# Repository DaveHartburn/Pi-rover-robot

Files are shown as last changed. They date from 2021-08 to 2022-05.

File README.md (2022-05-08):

# Pi-rover-robot

Repository for main code, libraries, hardware testing and simulator for a Raspberry Pi based rover robot.

Can I create an autonomous rover robot that can navigate around the garden, tracking it's location with BLE beacons, using a camera and image analysis to detect the lawn edge and other sensors to find and avoid other obsticles around the garden? Originally conceived with the intention of making an automated lawn mower (which may still happen) but the build and automation challenges are far more interesting first.

Blog posts detailing hardware build and software development can be found at https://samndave.org.uk/ourdoc/pi-rover-robot-project/

## piroverlib

The heart of most Python scripts is piroverlib.py. This contains two classes, piRover and pwmMotor.

### piRover class

| Function | Details |
| --- | --- |
| init(<list>) | Called with multiple arguments (below), depending on what hardware is installed |
|  * name="string"	| Give your robot a name |
|  * left=[a,b]		| List of a and b pins for left motor(s) |
|  * right=[a,b]	|	List of a and b pins for right motor(s) |
|  * load=1		|	Return load values with data |
|  * wifi=1		|	Return wifi RSSI and noise with data |
|  * button=p | Defines a pushbutton attached to pin p |
|  * pico=True | Use a pico slave for functions such as ultrasonic and pan/tilt mount |
|  * magneto=True	| Use a LSM303AGR magnetometer for heading info |
| stop() | Instantly stops both motors |
| fwFull(sp) | Sets both motors to full speed. sp positive for forward, sp negative for backwards. Zero will perform a stop |
| fwSpeed(sp) | Sets both motors to the speed sp |
| drive(l,r) | Drives the motors forward by setting the motors to the l & r values |
| js(x,y) | Drives the motors according to an analog joystick x and y axis calibrated to -100 to 100 |
| spin(sp) | Spins the rover on it's axis according to speed. Positive=clockwise |
| chSpeed(l,r) | Change the left and right motors by the l and r amount |
| getSensorData() | Returns data from all defined sensors |
| readLoad() | Returns only the current load |
| readWifi() | Returns wifi signal and noise levels as a list/tuple |
| getSonic(n) | Returns the ultrasonic distance value for a specific sensor or all if n is negative/missing |
| panAngle(a) | Sets the pan angle to a |
| panLeft(a) | Pans the camera to the left (or right if a is negative) |
| panCentre(a) | Sets the camera pan and tilt to centre (default positions) |
| tiltAngle(a) | Sets the tilt angle to a |
| tiltUp(a) | Tilts the camera up by angle a (down if a is negative) |
| getButton() | Returns the state of the pushbutton (0=pressed) |
| LSM303AGR Functions: | |
| magNormalise(m) | Internal function to normalise to calibrated values |
| getHeading([a, i]) | Get heading and chassis tilt, optional a attempts with interval i |
| turnToHeading(h, [s, f]) | Turn to a heading h, with speed s and force direction (1,-1) optional |

### pwmMotor class

| Function | Details |
| --- | --- |
| init(a,b) | Called when new motor object is created with the motor A & B BCM pins |
| stopPWM() | Internal use only. Used to stop a running PWM object |
| stop() | Instantly stops the motor and disabled PWM on the pin |
| full(sp) | Sets the motor to full speed. sp positive for forward, sp negative for backwards. Zero will perform a stop |
| setSpeed(sp) | Use PWM to set an analog speed between -100 and 100, with negative being backwards |

### driveByQueue
 
driveByQueue.py is an interface which implements a ZMQ queue and accepts a simple text command language. It directly calls functions in piroverlib.py, allowing one or more applications to send commands to the rover (or read sensor data), without having to run multiple piRoverLibs which may conflict. This aids web interface driving and also allows remote control.

Commands are supplied as a comma seperated list and it is quite sensitive to formatting.
 
e.g. "`chspeed,10,-10`" will increase the left motor by 10% while decreasing the right motor by 10%.
 
| Command	| Arguments	| Function |
| --- | --- | --- |
| stop	| None	| Stop |
| fwfull	| speed | positive or negative integer	Both motors forward or reverse at full power |
| fwspeed	| speed | -100 to 100	Sets both motors to speed |
| chspeed |	l, r	| Value to change speed of left and right motor |
| drive	| l, r	| Set absolute values for left and right motor |
| js	| x,y | Values between -100 and 100, send x and y joystick values |
| spin	| speed | -100 to 100,	Spin clockwise (positive) or anti-clockwise at given speed |
| panangle | a or 'mid' | Sets the pan angle or sets to centre |
| panleft | a | Pans the camera to the left (or right if a is negative) |
| pancentre | a | Sets the camera pan and tilt to centre (default positions) |
| tiltAngle | a | Sets the tilt angle to a |
| tiltUp | a | Tilts the camera up by angle a (down if a is negative) |
| getsens |	None	| Return all sensor data |
| getsonic | [n] | Get only the ultrasonic sensors with key sonicDist. Option to supply specific sensor number |
| quit	| None	| Quit the server |

## GPIO Wiring ##

Direct GPIO connections
 
| Pin# | Value | Connection| Pin# | Value | Connection |
| - | - | - | - | - | - |
| 1 | 3V3 | Breadboard 3.3v | 2 | 5V | Breadboard 5v |
| 3 | GPIO2 (SDA1, I2C) | PCA9685 | 4 | 5V | - |
| 5 | GPIO3 (SCL1, I2C) | PCA9685 | 6 | GND | Breadboard GND |
| 7 | GPIO4 | Front US trig | 8 | GPIO14 | Rear US trig |
| 9 | GND | - | 10 | GPIO15 | Rear US echo |
| 11 | GPIO17 | Front US echo | 12 | GPIO18 | MDD3A M1A |
| 13 | GPIO27 | Pushbutton | 14 | GND | - |
| 15 | GPIO22 | - | 16 | GPIO23 | - |
| 17 | 3V3 | - | 18 | GPIO24 | - |
| 19 | GPIO10 | - | 20 | GND | - |
| 21 | GPIO9 | - | 22 | GPIO25 | - |
| 23 | GPIO11 | - | 24 | GPIO8 | - |
| 25 | GND | - | 26 | GPIO7 | - |
| 27 | GPIO0 | - | 28 | GPIO1 | - |
| 29 | GPIO5 | - | 30 | GND | - |
| 31 | GPIO6 | - | 32 | GPIO12 | MDD3A M1B |
| 33 | GPIO19 | MDD3A M2A | 34 | GND | - |
| 35 | GPIO19 | MDD3A M2B | 36 | GPIO16 | - |
| 37 | GPIO26 | - | 38 | GPIO20 | - |
| 39 | GND | - | 40 | GPIO21 | - |

## Pi Pico Wiring ##

 | Pin# | Value | Connection | Pin# | Value | Connection |
 | - | - | - | - | - | - |
 | 1 | GP0 (UART0 Tx) | Pi Serial Rx (GPIO 15) | 40 | VBUS | - |
 | 2 | GP1 (UART0 Rx) | Pi Serial Tx (GPIO 14) | 39 | VSYS | - |
 | 3 | GND | Breadboard GND | 38 | GND | - |
 | 4 | GP2 | Servo 0, lower pan/tilt | 37 | 3v3_EN | - |
 | 5 | GP3 | Servo 1, upper pan/tilt | 36 | 3V3(OUT) | - |
 | 6 | GP4 | - | 35 | ADC_VREF | - |
 | 7 | GP5 | - | 34 | GP28 | - |
 | 8 | GND | - | 33 | GND | - |
 | 9 | GP6 | - | 32 | GP27 | - |
 | 10 | GP7 | - | 31 | GP26 | - |
 | 11 | GP8 | - | 30 | RUN | Pushbutton to GND |
 | 12 | GP9 | - | 29 | GP22 | - |
 | 13 | GND | - | 28 | GND | - |
 | 14 | GP10 | - | 27 | GP21 | - |
 | 15 | GP11 | - | 26 | GP20 | - |
 | 16 | GP12 | - | 25 | GP19 | - |
 | 17 | GP13 | - | 24 | GP18 | - |
 | 18 | GND | - | 23 | GND | - |
 | 19 | GP14 | - | 22 | GP17 (I2C0 SCL) | - |
 | 20 | GP15 | - | 21 | GP16 (I2C0 SDA) | - |
 
## To Do

- [x] Drivable app over wifi, can we drive anywhere in range of wifi?
- [] Proximity detection. Add to HUD and autonomous driving avoiding obstacles
- [] Directional sensing. Can we detect which direction we are facing and add suitable functions for turn to angle?
- [] Software vs Hardware PWM, power draw and test motor controller power
- [] QR code recognition - act when the camera recognises a QR code
- [] BLE beacon - can it detect a beacon and locate it?
- [] BLE triangulation - what if there were 4 beacons, can we accurately find our location?

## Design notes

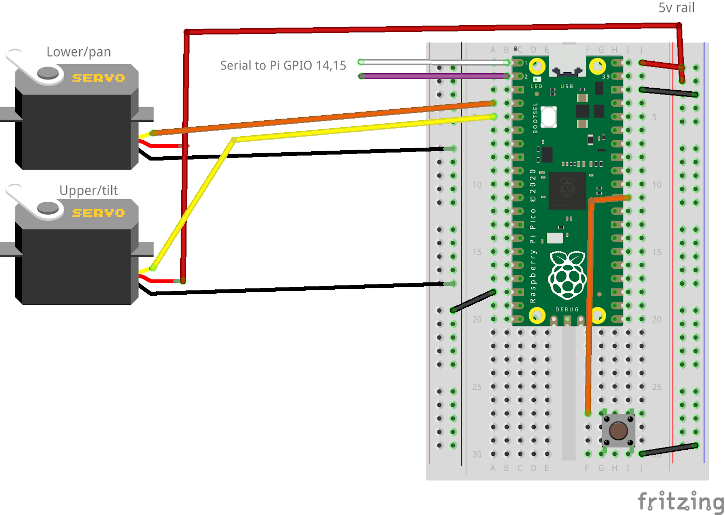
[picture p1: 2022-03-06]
schematics/pico_breadboard_bb.png

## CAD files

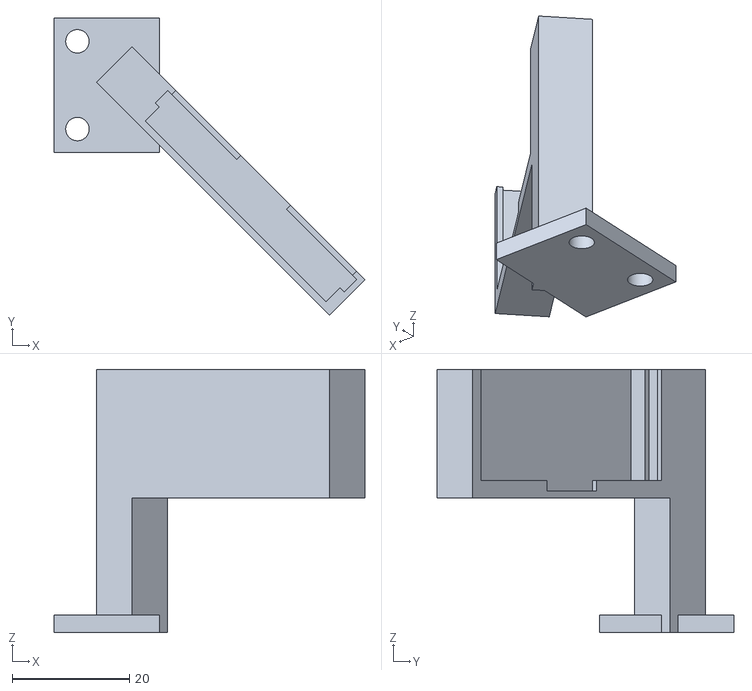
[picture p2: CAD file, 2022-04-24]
3dPrints/overWheelSR04_right.stl
53.1 x 50.8 x 45.0

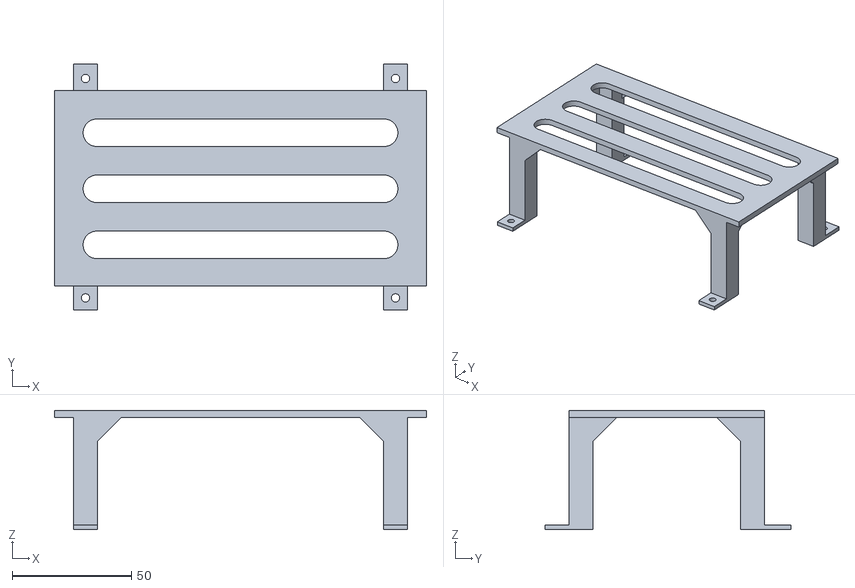
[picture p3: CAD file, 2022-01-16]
3dPrints/elevatedBBholder.stl
156.0 x 103.0 x 50.0

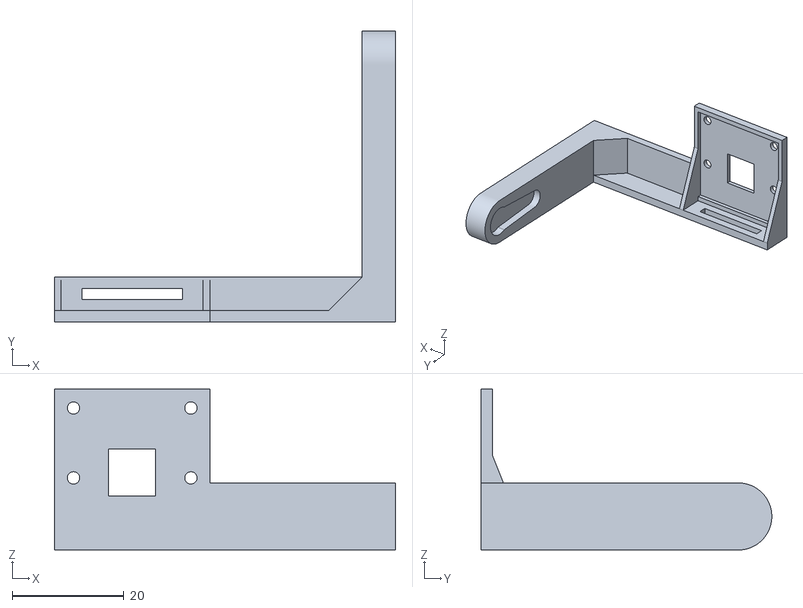
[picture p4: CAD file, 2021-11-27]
3dPrints/pan_tilt_cam_arm.stl
61.0 x 52.0 x 28.8

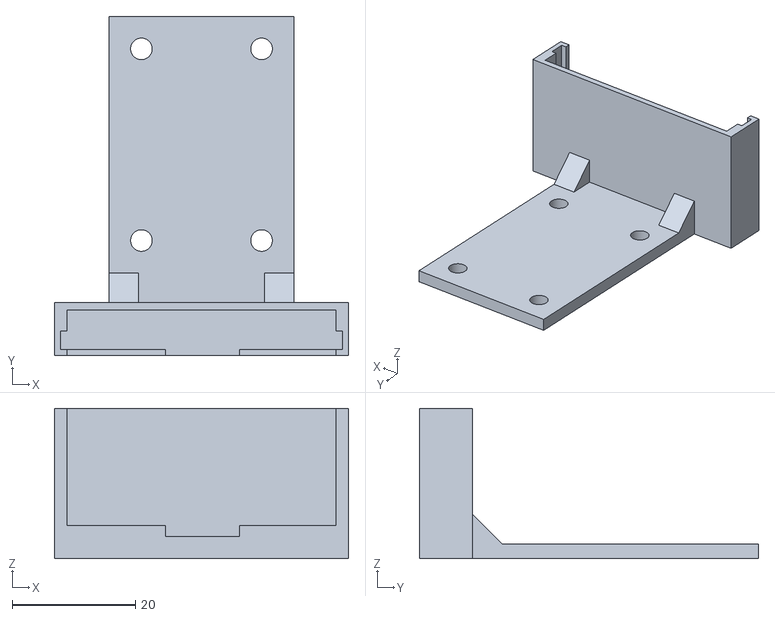
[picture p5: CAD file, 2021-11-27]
3dPrints/hc_sr04_mount.stl
47.7 x 55.0 x 24.4

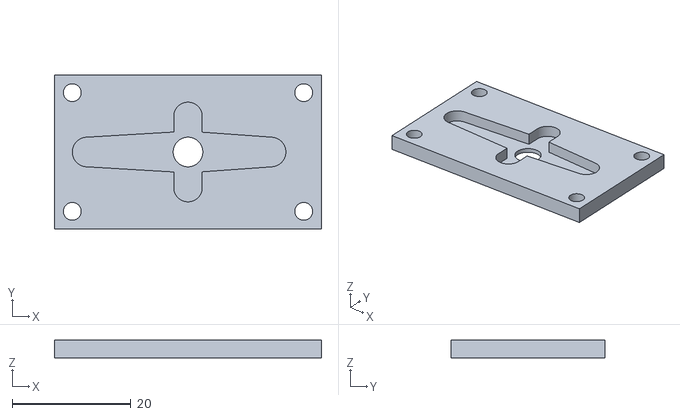
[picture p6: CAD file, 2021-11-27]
3dPrints/pan_tilt_mount_lower_base.stl
45.0 x 26.0 x 3.00

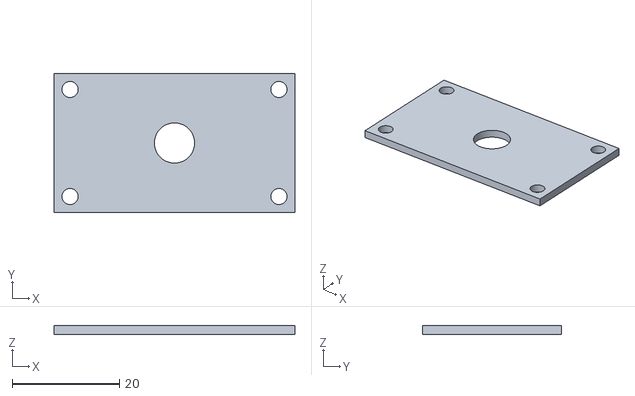
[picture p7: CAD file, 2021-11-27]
3dPrints/pan_tilt_mount_upper_base.stl
45.0 x 26.0 x 1.60

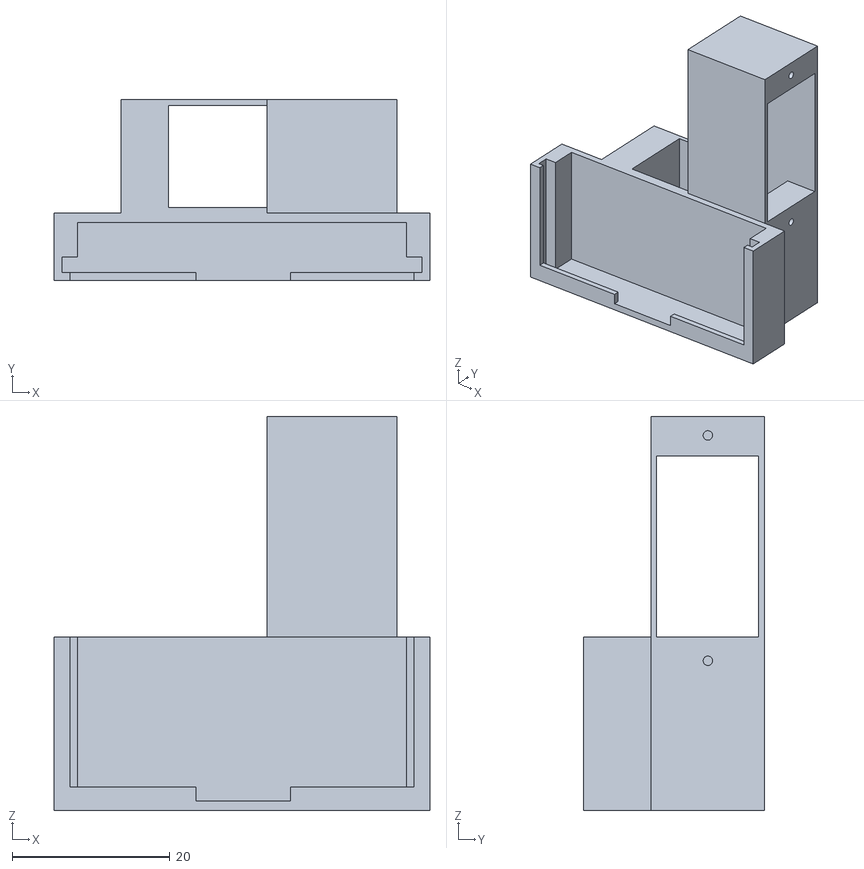
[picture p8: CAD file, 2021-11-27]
3dPrints/pan_tilt_mount_body.stl
47.7 x 23.0 x 50.0

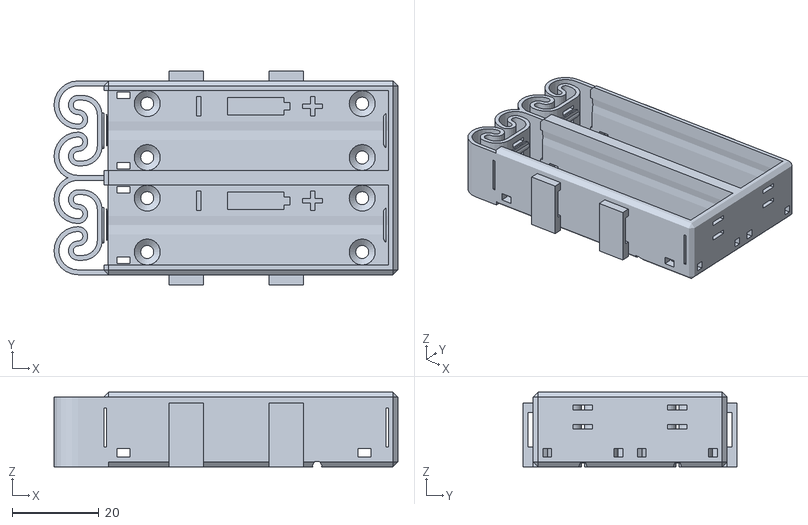
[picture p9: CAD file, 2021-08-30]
3dPrints/18650_nickle.stl
79.2 x 49.4 x 17.2

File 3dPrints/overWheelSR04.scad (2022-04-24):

/* HC-SR04 over wheel holder
 * For Pi Rover Robot
  */

$fn=256;

// What to show
showWheel=0;    // Will also show chassis
showSensor=0;
showHolder=1;

rightWheel=1;   // 1 for right wheel, 0 for left

sensorAngle=45;
sensHeight=45;

if(showWheel==1) {
    drawWheelChassis();
}

if(showSensor==1) {
    drawSensor();
}

if(showHolder==1) {
    if(rightWheel==1) {
        sensorHolder();
    } else {
        mirror([1,0,0]) {
            sensorHolder();
        }
    }
}

module sensorHolder() {
    w=45.3+2.4;     // Width of the main unit
    sd=8.6;   // Sensor holder depth
    shh=22;   // Sensor holder height

    plateTh=3;
    plateW=18;
    plateL=23;
    hole=4;     // Screw hole size

    // Sensor holder
    rotate([0,0,180-sensorAngle]) translate([1-w,-3,sensHeight-shh])  {
        // Sensor holder
        difference() {
            cube([w,sd,shh]);
            // slot
            translate([1,-1,1.2]) cube([45.3+0.4,5,shh+1]);
            translate([2,3,1.2]) cube([45.3+0.4-2,4.4,shh+5]);
        }
        // Retaining supports
        translate([0,0,1]) cube([18,1,2]);
        translate([30,0,1]) cube([17,1,2]);
        translate([1,0,0]) cube([1,1,shh]);
        translate([45.3+0.4,0,0]) cube([1,1,shh]);
        
        // Draw pole
        translate([w,0,shh-sensHeight]) {
            cube([sd,sd,sensHeight]);
        }
    }
    // Base plate
    translate([-plateW, sd/2-plateL/2-2, 0]) {
        difference() {
            cube([plateW,plateL,plateTh]);
            // Screw holes
            translate([hole,hole,-1]) {
                cylinder(h=plateTh+2, d=hole);
            }
            translate([hole,plateL-hole,-1]) {
                cylinder(h=plateTh+2, d=hole);
            }
        }
    }
}

module drawSensor() {
    translate([0,0,sensHeight]) {
        rotate([-90,0,-sensorAngle]) {
            hcsr04();
        }
    }
}

module drawWheelChassis() {
    // Chassis - very crude
    // Dimensions
    w=60;
    l=100;
    h=12;
    offset=16;  // How much lower is the board to the wheel?
    
    color("Peru") {
        translate([-w,-l/2,-h]) cube([w,l,h]);
    }
    diam=83;
    tyrew=33;
    color("darkgrey") {
        translate([0,0,offset-diam/2]) {
            rotate([0,90,0]) cylinder(d=diam, h=tyrew);
        }
    }
}

module hcsr04() {
    // Draws a HC-SR04 sensor module
    w=45.3;
    h=20.3;
    d=1.6;
    hole=1.5;
    ho=1.3; // Hole offset (same in X and Y);
    srdiam=16;
    difference() {
        color("darkblue") cube([w,h,d]);
        // Cut holes
        translate([ho,ho,-1]) cylinder(d=hole, h=d+2);
        translate([ho,h-ho,-1]) cylinder(d=hole, h=d+2);
        translate([w-ho,ho,-1]) cylinder(d=hole, h=d+2);
        translate([w-ho,h-ho,-1]) cylinder(d=hole, h=d+2);
    }
    // Sender and receiver
    translate([9,10,d]) color("silver") cylinder(d=16, h=12);
    translate([w-9,10,d]) color("silver") cylinder(d=16, h=12);
    // Oscillator
    ow=9.8;
    oh=3.4;
    od=2.5;
    color("silver") translate([19.5,17.9,d]) {
        hull() {
            cylinder(d=oh,h=od);
            translate([6.6,0,0]) cylinder(d=oh,h=od);
        }
    }
    
    // Pins
    translate([17.5,0,-2.4]) {
        color("black") cube([10.4,2.4,2.4]);
        for(i=[0:3]) {
            translate([1.1+i*2.54,1.1,-1.6]) {
                color("silver") {
                    cube([0.6,0.6,1.6]);
                    translate([0,-6.9,0]) cube([0.6,7.5,0.6]);
                }
            }
        }
    }
}

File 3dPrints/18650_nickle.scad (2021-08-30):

/* 18650 holder with nickel strip.
 * The Flexing Battery holder with a slot cut out and grips
 * https://www.thingiverse.com/thing:456900
 *
 * Download the SCAD file for this and save it is flexbatter_lib.scad
 *
 * Not doing this as a remix as multiple cells are made from the same holder
 * butted up to each other. We need to add grips to the outsides
 */

use <flexbatter_lib.scad>

bat=2;   // Number of batteries
stripW=8;   // Width of strip
stripT=0.2; // Thickness of strip

// The sizes calculated for a single cell by flexbatter
holdSize=[67.74, 22.88, 17.16];
// Move battery holder to origin. The spring remains in negative X,
// but this is useful as we can make our slot at x=0
translate([0,holdSize.y/2,0]) {
    // Cut out slot at spring
    cw=stripW+1;    // Give a margin
    ct=stripT+0.4;
    ch=4.5;           // Manually defined height of cut out
    difference() {
        flexbatter18650(n=bat);
        // - end
        translate([0,-holdSize.y,ch]) {
            cube([ct,holdSize.y*(bat+1),cw]);
        }
        // + end
        translate([65,-holdSize.y,ch]) {
            cube([ct,holdSize.y*(bat+1),cw]);
        }
    }
}

// Add strip grips, move down the holder a little
translate([15,0,0]) stripGrip(r=1);
translate([65-27,0,0]) stripGrip(r=1);
translate([15,holdSize.y*bat-(1.2*(bat-1)),0]) stripGrip(r=0);
translate([65-27,holdSize.y*bat-(1.2*(bat-1)),0]) stripGrip(r=0);

module stripGrip(r=1) {
    // Grips or handles to tuck the end of the nickel strips into
    // r=1, right side, r=0, left side
    gap=1+stripT;
    t=1.2;    // Thickness of the grip top (the bottom goes to the base for easy printing)
    s=1.2;  // Thickness of the grip side
    l=8;    // Length of grip (how far down the side)
    ch=4.5;  // How high we have done the cut out
    
    translate([0,r*-(gap+s),0]) {
        difference() {
            cube([l,gap+s,ch+stripW+1+t]);
            if(r==1) {
                translate([-1,s,ch]) cube([l+2,gap,stripW]);
            } else {
                translate([-1,0,ch]) cube([l+2,gap,stripW]);
            }
        }
    }
}

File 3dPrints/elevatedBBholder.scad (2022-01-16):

/* Elevated breadboard holder
 * Dave Hartburn - January 2022
 * Used to hold three breadboards in an elevated position
 * above my Pi Rover robot (for development)
 *
 * The total width for 3 boards is greater than the width
 * of the wheels, so I need to account for this when positioning the stands
 */
$fn=256;


bbsize=[54,82,9];   // Size, excluding locking tabs
numBoards=3;
elevation=50;
supportTh=3;        // How thick to make main bit the boards rest on
maxLegWidth=140;    // Width of gap between wheels, do not make wider
footScrewHole=3.5;

showBoards=1;
boardsWidth=bbsize.x*numBoards;
echo("Total width = ", boardsWidth, "mm");

if(showBoards==1) {
    translate([0,0,elevation]) {
        draw_breadboards(numBoards);
    }
}

// Supporting board
translate([0,0,elevation-supportTh]) {
    difference() {
        cube([boardsWidth, bbsize.y,supportTh]);
        // Cut out strips so it is not completely solid
        strips=3;
        stripWidth=12;
        xedge=12;
        gap=(bbsize.y-(stripWidth*strips))/(strips+1);
        for(i = [1:strips]) {
            translate([xedge,gap*i+stripWidth*(i-1),-1]) {
                //cube([boardsWidth-xedge*2,gap,supportTh+2]);
                stadium(boardsWidth-xedge*2,gap,supportTh+2);
            }
        }     
    }
}
// Legs
legx=10;
legy=10;
// This code will fail if boards are narrower than min leg
xoffset=(boardsWidth-maxLegWidth)/2;
echo("xoffset=", xoffset);
translate([xoffset,0,0]) leg(1,legx,legy,elevation-supportTh);
translate([xoffset,bbsize.y-legy,0]) leg(2, legx,legy,elevation-supportTh);
translate([boardsWidth-legx-xoffset,bbsize.y-legy,0]) leg(3, legx,legy,elevation-supportTh);
translate([boardsWidth-legx-xoffset,0,0]) leg(4, legx,legy,elevation-supportTh);


module leg(pos,x,y,h) {
    // Produces a square leg with a foot and supports
    // pos is clockwise from 1 where 1 is the front left corner
    p=pos-1;
    f=5;    // Fraction of x to make triangular supports
    translate([x*floor(p/2),y*ceil(p%1.5),0]) {
        rotate([0,0,-90*p]) {
            cube([x,y,h]);
            // Triangular supports
            translate([x,0,h]) {
                rotate([-90,0,0]) raPrism(x,x,x/f);
            }
            translate([x/f,y,h]) {
                rotate([-90,0,90]) raPrism(x,x,x/f);
            }
        }
        // Foot
        translate([-x*floor(p/2),-y+y*ceil(p%1.5),0]) {
            difference() {
                cube([x,y+1,2]);
                translate([x/2,y/2,-1]) {
                    cylinder(d=footScrewHole, h=4);
                }
            }
        }

    }
}

module breadboard() {
    // Shows a sinle bit of standard size breadboard
    color("white") {
        difference() {
            cube(bbsize);
            // Remove middle dip to give a bit more feature
            dip=3;
            translate([bbsize.x/2-dip/2, -1, bbsize.z-dip]) {
                cube([dip,bbsize.y+2,dip+1]);
            }
        } 
        // Locking tabs - short edge
        for(x = [0:2]) {
            translate([4.5+x*22,-0.7,0]) cylinder(d=2.2,h=4.65);
        }
        // Long edge
        translate([-0.7,13.8,0]) cylinder(d=2.2,h=4.65);
        translate([-0.7,bbsize.y-13.8,0]) cylinder(d=2.2,h=4.65);
    }
    
    // Add a couple of surface features to make it a little more
    // interesting
    translate([1.5,10,bbsize.z]) {
        color("blue") cube([0.5,bbsize.y-20,0.1]);
    }
    translate([bbsize.x-8,10,bbsize.z]) {
        color("blue") cube([0.5,bbsize.y-20,0.1]);
    }
    translate([8,10,bbsize.z]) {
        color("red") cube([0.5,bbsize.y-20,0.1]);
    }
    translate([bbsize.x-1.5,10,bbsize.z]) {
        color("red") cube([0.5,bbsize.y-20,0.1]);
    }
}

module draw_breadboards(x) {
    // Draws x breadboards side by side
    for(y = [0:x-1]) {
        translate([y*bbsize.x,0,0]) {
            breadboard();
        }
    }
}
module stadium(x,y,z) {
    // Make a stadium/oblong shape with the two x ends rounded
    translate([y/2,y/2,0]) cylinder(h=z,d=y);
    translate([y/2,0,0]) cube([x-y,y,z]);
    translate([x-y/2,y/2,0]) cylinder(h=z,d=y);

}

module raPrism(x,y,z) {
    // Draws a right angle prism on it's side
    polyhedron(
        points=[
            [0,0,0],    // 0
            [0,0,z],    // 1
            [x,0,z],    // 2
            [x,0,0],    // 3
            [0,y,z],    // 4
            [0,y,0]     // 5
        ], faces=[
            [0,1,2,3],  // Front face along X axis
            [5,4,1,0],  // Side face along Y axis
            [5,3,2,4],  // Side diagonal
            [1,4,2],    // Top triangle
            [0,3,5]     // Bottom triangle
        ]
    );
}

module raPrismUpright(x,y,z) {
    // Draws an upright right angle prism, flat back to the rear
    polyhedron(
        points=[
            [0,0,0],    // 0
            [0,y,0],    // 1
            [x,y,0],    // 2
            [x,0,0],    // 3
            [0,y,z],    // 4
            [x,y,z]     // 5
        ], faces=[
            [3,2,1,0],  // Base
            [2,5,4,1],  // Back
            [0,4,5,3],  // sloped front
            [0,1,4],    // left side
            [3,5,2]     // right side
        ]
    );
}

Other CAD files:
3dPrints/overWheelSR04_left.stl
3dPrints/hc_sr04_mount.scad
3dPrints/pan_tilt_mount.scad
3dPrints/sg90_capped.scad

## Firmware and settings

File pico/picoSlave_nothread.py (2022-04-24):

# Pi Rover Robot - Pico slave code
# Dave Hartburn - January 2022
#
# Slave processes for handling various IO functions for the main Pi controller
# Communicates over serial to the Pi.
#
# Connected hardware:
#   GP0,1  - UART Tx and Rx to Pi
#   GP2 - Servo 0, lower pan/tilt
#   GP3 - Servo 1, upper pan/tilt
#
# Incoming command format:
#   ping - Will respond with the string 'beep' - used to test for life
#   quit - stop all execution, a reset will be required to restart
#   dataRequest - Send the data array showing sensor and servo positions

# Import libraries
from machine import Pin
import machine
import time
import json

debugOut = True       # Use dprint(str) rather than print(str), set to false to prevent print output

activate = False       # True if actively checking sensors and sending serial data
sendFreq = 250         # How often to send data in ms
sensorFreq = 250       # How often to check sensors in ms
sonicTimeout = 50000    # Timeout in ns

hwData={}             # Build dictionary of hardware data to return current status to Pi
hwData["msg"]=""      # Used to send messages back

# List of attached servos as array, [pin,min angle, max angle, calibrarion angle]
# Leave blank if no servos
servos=[ [2,25,150,-14],    # Pan servo (index 0)
         [3,30,120,0] ]   # Tilt servo (index 1)
servoPWM=[]          # Array of PWM objects for each servo

# List of sonic sensors. Name, triger pin, echo

sonicList= [
    ["front", Pin(4, Pin.OUT), Pin(5, Pin.IN)],
    ["left", Pin(6, Pin.OUT), Pin(7, Pin.IN)],
    ["right", Pin(8, Pin.OUT), Pin(9, Pin.IN)],
    ["rear", Pin(15, Pin.OUT), Pin(14, Pin.IN)]
    ]

# Internal timers
nextSend = 0         # Time of next data send
nextSensor = 0       # Next time to check the sensors


# Internal pin for activity
led=Pin(25, Pin.OUT)

# Initialise the UART
uart = machine.UART(0, 115200)

# ********* Functions *****************
def dprint(str):
    if(debugOut):
        print(str)
# End of debugPrint

def flash(l,n, i):
    # Flash the led l, n times, with an interval i
    for x in range(n*2):
        l.toggle()
        time.sleep(i)
    l.toggle()
    
# UART function
def sendData(str):
    # Sends data over the serial UART
    # Add new line to terminate string
    #print("Sending: ", str)
    uart.write(str+'\n')

def sendhw():
    # Send the hwData array as JSON object
    jsonOut=json.dumps(hwData)
    #dprint(jsonOut)            
    sendData(jsonOut)
     
def receiveData():
    toReturn=[]
    dataIn = ""
    
    while uart.any():
        # In a fast enough loop, this may be called before the string
        # has completed sending. This loop will continue until the incoming
        # data has completed. On exception it will send what string it has
        # so far
        # However if the sender sends data too quickly, then all commands
        # merge into one, construct array "toReturn" and send a list if needed
        rawIn = uart.readline()
        # print(rawIn)
        # print("".join("%02x " % b for b in rawIn))
        
        # Raw data is as a byte stream. Convert
        # Need to use a try/except as control characters may cause an issue
        try:
            dataIn += str(rawIn.decode('utf-8'))
            #print("Incoming :", dataIn)
        except:
            pass
    
    # Split commands on new line
    toReturn=dataIn.split('\n')
    
    #print("Array of commands")
    #print(toReturn)
    return toReturn

# Servo functions
def setServoCycle (obj, pos):
    obj.duty_u16(pos)
    
def setServoAngle (s, a):
    # Check servo is in the range of defined servos
    # Out of range is silently ignored
    if(s<len(servoPWM)):
        # Is fine, check angle is in range and if not adjust
        # to min or max value
        
        if(a<servos[s][1]):
            a=servos[s][1]
        if(a>servos[s][2]):
            a=servos[s][2]
        
        # Updata hardware data array
        hwData["servos"][s]=a

        # Add calibration angle
        a=a+servos[s][3]
        
        d = int(a/180*8000+1000)
        dprint("Angle={}, d={}".format(a,d))
        setServoCycle(servoPWM[s], d)
# End of set servo angle

def changeServoAngle (s, a):
    # Change the angle of servo s by a degrees
    if(s<len(servoPWM)):
        n=hwData["servos"][s]+a
        setServoAngle(s,n)

# Ultrasonic functions
def readSonic(trig, echo):
    # Read the distance from an ultrasonic sensor,
    # return in cm. -1 = error
    
    # Any reading above this value is considered an error
    timeOut=time.ticks_us()+sonicTimeout
    
    callTime=time.ticks_us()
    startTime=callTime    # Set a default value time. We can sometimes get
    stopTime=callTime     # Get a variable not set error
    
    trig.low()
    time.sleep_us(2)   
    trig.high()
    time.sleep_us(5)
    trig.low()
    
    # Save start time
    #print("Waiting for echo to go to zero")
    while (echo.value()==0 and time.ticks_us()<timeOut):
        startTime = time.ticks_us()
    
    # Save end time
    #print("Waiting for echo to go to one")
    while (echo.value()==1 and time.ticks_us()<timeOut):
        stopTime = time.ticks_us()
      
    #print("Echo returned / time out")
    
    if(time.ticks_us()>timeOut):
        # Time out error
        dist=-1
    else:
        elTime=stopTime-startTime
        dist=round((elTime*0.0343)/2,2)

    return dist
# End of readSonic

def readAllSonics():
    i=0
    for s in sonicList:
        d = readSonic(s[1], s[2])
        #dprint("Sonic {}, distance={} cm".format(s[0],d))
        hwData["sonics"][i][1]=d
        i+=1
    #print(hwData)
    
# ******** Main code ******************

dprint("Hello from pico slave")

# Show life
flash(led,3,0.5)

# Initialise servos if present
if(servos==[]):
    dprint("No servos defined")
else:
    # Servos present, create array for servo positions in hwData
    hwData["servos"]=[]
    i=0
    for srv in servos:
        dprint("Init servo on pin {}".format(srv[0]))
        # Create PWM object
        p=machine.PWM(Pin(srv[0]))
        p.freq(50)
        # Add to hwData array
        hwData["servos"].append(90)
        # Add to PWM array
        servoPWM.append(p)
        # Init in mid position
        setServoAngle(i, 90);
        i+=1

# Initialise ultrasonic sensors if present
if(sonicList==[]):
    dprint("No ultrasonics defined")
else:
    # Sonics present, create array for distance readings in hwData
    hwData["sonics"]=[]
    for s in sonicList:
        dprint("Init ultrasonic "+s[0])
        hwData["sonics"].append([s[0], -1])
        
dprint("Initial hwData:")
dprint(hwData)

# Main loop
while True:
    if uart.any():
        # Data present
        incData=receiveData()
        dprint("Data received: ")
        dprint(incData)
        
        # Examin individual messages
        for msg in incData:
            # Break the message into CSV
            csvin=msg.split(',')
            # Take the command off the front
            cmd=csvin.pop(0)
            dprint("Received command "+cmd)
            #dprint(csvin)
            
            # Try and except deals with list index errors due
            # to incorrect arguments
            if(cmd=="quit"):
                break
            elif(cmd=="ping"):
                #sendData("beep")
                hwData["msg"]="beep-"+str(time.time())
            elif(cmd=="panangle"):
                try:
                    setServoAngle(0,int(csvin[0]))
                except:
                    pass
            elif(cmd=="panleft"):
                try:
                    changeServoAngle(0,int(csvin[0]))
                except:
                    pass
            elif(cmd=="tiltangle"):
                try:
                    setServoAngle(1,int(csvin[0]))
                except:
                    pass
            elif(cmd=="tiltup"):
                try:
                    changeServoAngle(1,-int(csvin[0]))
                except:
                    pass
            elif(cmd=="servoangle"):
                try:
                    setServoAngle(int(csvin[0]),int(csvin[1]))
                except:
                    pass
            elif(cmd=="servoleft"):
                try:
                    changeServoAngle(int(csvin[0]),int(csvin[1]))
                except:
                    pass
            elif(cmd=="datarequest"):
               sendhw()
            elif(cmd=="activate"):
                activate=True
                nextSend=0
            elif(cmd=="deactivate"):
                activate=False
        # End of for msg in incData
    # End of if uart.any()
    
        
    # Do we need to check sensors and send data?
    if(activate):
        # Are sensor readings required
        if(nextSensor<time.ticks_ms()):
            readAllSonics()
            nextSensor=time.ticks_ms()+sensorFreq
            
        # Time to send data
        if(nextSend<time.ticks_ms()):
            #dprint("Sending data")
            sendhw()
            nextSend=time.ticks_ms()+sendFreq
            
# End of main loop
           
uart.write("Terminating....\n")
dprint("Completed")

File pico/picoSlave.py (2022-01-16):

# Pi Rover Robot - Pico slave code
# Dave Hartburn - January 2022
#
# Slave processes for handling various IO functions for the main Pi controller
# Communicates over serial to the Pi.
#
# Connected hardware:
#   GP0,1  - UART Tx and Rx to Pi
#   GP2 - Servo 0, lower pan/tilt
#   GP3 - Servo 1, upper pan/tilt
#
# Incoming command format:
#   ping - Will respond with the string 'beep' - used to test for life
#   quit - stop all execution, a reset will be required to restart
#   dataRequest - Send the data array showing sensor and servo positions


from machine import Pin, PWM
import machine
import time
import _thread
import json

led=Pin(25, Pin.OUT)

debugOut = True    # Use debug(str) rather than print(str), set to false to prevent print output
checkSensors = True       # Flag - setting to false will terminate second thread

# Define hardware
servos=[2,3]         # List of servo pins
servoPWM=[]
servoBits=False

uart = machine.UART(0, 115200)
#print(uart)

#pwm = PWM(Pin(2))
#pwm.freq(50)


# ******** Functions ******************************
# Sensor thread - continual loop until checkSensors is set to false
# Will toggle the onboard LED on each operation to show activity and life
def sensorThread():
    nextCheck=0    # When to next check the sensors
    togInterval=1000   # Just toggle the LED for now
    print("checkSensors=", checkSensors)
    while True:
        if(checkSensors==False):
            break
        if(time.ticks_ms()>nextCheck):
            # No sensors, toggle LED
            led.toggle()
            nextCheck=time.ticks_ms()+togInterval
            
    # End of 'infinite while loop
    # Thread complete, checkSensors set to false
# End of sensorThread

def dprint(str):
    if(debugOut):
        print(str)
# End of debugPrint

def sleep_nb_ms(t):
    # Use the time to sleep for t microseconds without blocking
    # i.e. not using time.sleep()
    endTime=time.ticks_ms()+t
    while endTime>time.ticks_ms():
        pass

def sleep_nb(t):
    # None blocking sleep for t seconds
    sleep_nb_ms(t*1000)
    
def sendData(str):
    # Sends data over the serial UART
    # Add new line to terminate string
    #print("Sending: ", str)
    uart.write(str+'\n')
    
def receiveData():
    dataIn = ""
    
    while uart.any():
        # In a fast enough loop, this may be called before the string
        # has completed sending. This loop will continue until the incoming
        # data has completed. On exception it will send what string it has
        # so far
        rawIn = uart.readline()
        #print(rawIn)
        # Raw data is as a byte stream. Convert
        # Need to use a try/except as control characters may cause an issue
        try:
            dataIn += str(rawIn.decode('utf-8').strip())
            #print("Incoming :", dataIn)
        except:
            pass
    return dataIn

# **** Servo functions *****
def setServoCycle (obj, pos):
    obj.duty_u16(pos)
    
def setServoAngle (s, a):
    d = int(a/180*8000+1000)
    #print("Angle=",a,"d=",d)
    setServoCycle(servoPWM[s], d)
    
# ******** Main code *************

# Start sensor checker in new thread
_thread.start_new_thread(sensorThread, ())
#sensorThread()   # Uncomment for single thread/testing

sendData("Starting main thread")

print("Testing delay of 5 seconds");
sleep_nb(5)
print("Done")

#Initialise servos
for srv in servos:
    #dprint("Init servo on pin {}".format(srv))
    #p=PWM(Pin(srv))
    #p.freq(50)
    #servoPWM.append(p)
    pass

if servoBits:

    Angles = [56, 157 ,4 ,89 ,39, 170, 2, 123]
    for a in Angles:
        #print("Setting angle ", a);
        setServoAngle(0, a)
        sleep_nb(2)
    for pos in range(0,160,2):
        setServoAngle(0, pos)

print("10 second delay")
sleep_nb(10)
print("At end of delay")

#  
# setServoAngle(0, 45)
# time.sleep(2)
# setServoAngle(0, 90)

# Main loop
while True:
    if uart.any():
        msg=receiveData()
        dprint("Message received: \"{}\"".format(msg))
        if(msg=="quit"):
            checkSensors=False
            break
        if(msg=="ping"):
            sendData("beep")
        elif(msg=="dataRequest"):
            # Return whole data array as JSON
            sendData("null")
            
uart.write("Terminating....\n")
dprint("Completed")

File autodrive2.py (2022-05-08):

#!/usr/bin/python

# Autodrive 1 - A basic automated driving using the ultrasonic sensors
#   - Drive forward until it gets within a set distance of an object
#   - Look 45 degrees left and right, then turn the direction that is most clear
#	- If both directions show less than the set distance, then back up a bit
#	- If both are equal (within a threshold) then turn the same direction as the last turn (default right)
#
# Modified from original to use sonic sensors and servos on a pico slave device
#
# Dave Hartburn - December 2021
#

# Standard libraries
import time
import json
import RPi.GPIO as GPIO


# Include local pirover library
from piroverlib import piRover

# Array to hold data from the pico
picoData=[]

# Define constants
fwSpeed = 50			# Percent forward speed
bwSpeed = 30			# Percent backwards speed (is negated in function, don't make negative here!)
turnAngle = 50			# Spin rate
fwMinDist = 20			# cm distance to stop when going forward
bwMinDist = 15			# cm distance to stop when going backwards
lMinDist = 15			# cm distance to veer away from left side
rMinDist = 15			# cm distance to veer away from right side
sonicRead = 0.2			# Interval to wait between sonic sensor readings

backupTime = 2			# Number of seconds to run backwards for
turnAngle = 45			# Angle to turn
turnSpeed = 80			# Speed to turn
quitDist = 4			# Quit if both sensors read less than this distance
panLook = 45			# Amount to look left and right

# Define pin numbers [A, B]
leftPins=[18,12]
rightPins=[13,19]

pushButton=27		# Breadboard pushbutton

debugDelay=0		# How much to slow down operations to allow debugging and sense checks

# ********* Functions ******************
def backup():
	print("Backing up")
	backing=True
	pirover.fwSpeed(0-bwSpeed)
	endTime=time.time()+backupTime
	while backing:
		d = rearS=picoData["pico"]["sonics"][3][1]
		if(d<bwMinDist):
			# Hit minimum distance, stop and end
			pirover.stop()
			backing=False
		if(time.time()>endTime):
			pirover.stop()
			backing=False
		time.sleep(sonicRead)
	print("Done backing up")
	time.sleep(debugDelay)
	
def lookAbout():
	# Look both ways and retun distances as pair [left, right]
	global pirover
	sl=1			# Time to sleep between readings
	# Set to middle
	pirover.panAngle("mid")
	# Look left
	pirover.panLeft(panLook)
	time.sleep(sl)
	l=pirover.getSonic(0,4,True)
	# Look right
	pirover.panLeft(panLook*-2)
	time.sleep(sl)
	r=pirover.getSonic(0,4,True)
	
	# Return to middle
	pirover.panAngle("mid")
	return [l[0], r[0]]
	
def button_callback(channel):
	# Call back when the button is pressed. Stop the robot and quit
	global pirover
	pirover.stop()
	pirover.picoDeactivate()
	GPIO.cleanup()
	print("Emergency STOP!!")
	quit()
	
	
# ************ CHANGE THIS, need to take l and r value	
def turn_to_clearest(l, r):
	# Function to turn in the direction of the clearest route
	# l ,r are reported distances

	turn=0
	
	# If left comes back -1, turn right if sensible otherwise turn left
	if(l==-1):
		if(r==-1):
			# No sensible reading, quit
			print("No sonic readings, doing nothing")
			return
		if(r>rMinDist):
			print("No left reading, but right is clear, turning right")
			pirover.turnByHeading(turnAngle, speed=turnSpeed)
		else:
			print("No left reading, and right is not clear, try turning left")
			pirover.turnByHeading(-turnAngle, speed=turnSpeed)
	elif(r==-1):
		if(l>lMinDist):
			print("No right reading, and left is clear, turning left")
			pirover.turnByHeading(-turnAngle, speed=turnSpeed)
		else:
			print("No right reading, and left is not clear, try turning right")
			pirover.turnByHeading(turnAngle, speed=turnSpeed)
	elif(l>=r):
		# More distance to left, spin left (anti-clockwise)
		print("Left is clear, turning left")
		pirover.turnByHeading(-turnAngle, speed=turnSpeed)
	else:
		# More distance to right, spin right (clockwise)
		print("Right is clear, turning right")
		pirover.turnByHeading(turnAngle, speed=turnSpeed)

	time.sleep(debugDelay)
#  End of turn_to_clearest

def tooClose(frontS, leftS, rightS):
	# Return false if no sensor is within minimum distance
	if(frontS>-1 and frontS<fwMinDist):
		print("Front too close")
		return True
	if(leftS>-1 and leftS<lMinDist):
		print("Left too close")
		return True
	if(rightS>-1 and rightS<rMinDist):
		print("Right too close")
		return True
	return False
		
# Testing pico comms, should never be called during normal operation
# Suggest quitting after calling this
def testPico():
	print("Testing pico")
	print("Activate pico")#
	pirover.picoActivate()
	
	# Testing data receive
	for i in range(0,1):
		picoData=pirover.getdata()
		print(picoData)
		time.sleep(1)
	
	print("Testing servos at 30 degrees")
	pirover.panAngle(30)
	pirover.tiltAngle(30)
	time.sleep(2)
	print("Return servos to 90 degrees")
	pirover.panAngle(90)
	pirover.tiltAngle(90)
		
	print("Shutdown pico")
	pirover.picoDeactivate()
# End of testPico
	
	
# ********* End of functions ***********


print("AutoDrive 2 started, using magnetometer and accelerometer....")
#pirover=piRover(left=leftPins, right=rightPins)
pirover=piRover(left=leftPins, right=rightPins, pico=True, magneto=True)

# Set up button and call back. Not using the button as part of the pirover library, so
# that we can define the emergency stop call back here
GPIO.setmode(GPIO.BCM)
GPIO.setwarnings(False)
GPIO.setup(pushButton, GPIO.IN, pull_up_down=GPIO.PUD_UP)
GPIO.add_event_detect(pushButton, GPIO.RISING, callback=button_callback, bouncetime=100)


# Test mode, comment out
#testPico()
#quit()

# Start the pico processes
pirover.picoActivate()

drSpeed = fwSpeed		# Start driving forward

# Start running then enter loop, checking positions as we go
pirover.fwSpeed(drSpeed)
runLoop = True
errorStopped = False	# Flag if motors were stopped because of error
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

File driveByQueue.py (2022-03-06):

#!/usr/bin/python

# driveByQueue - Listens for input on a lightweight queue and drives the rover
# Essentially a proxy which executes the commands on the queue. Uses ZeroMQ
#
# Dave Hartburn - September 2021

# Standard libraries
import time
import zmq
import json
import sys

# Include local pirover library
from piroverlib import piRover

# Enable queue server
context = zmq.Context()
socket = context.socket(zmq.REP)
socket.bind("tcp://*:5555")

# Define pin numbers [A, B]
leftPins=[18,12]
rightPins=[13,19]
pantilt=[0,1]		# Servo slots on PCA9685
# Ultrasonic pins (GPIO numbers) are a list of pairs for each sensor, trigger & echo
sonicPins=[ [4,17], [14,15] ]

print("driveByQueue started")
#pirover=piRover(left=leftPins, right=rightPins)
pirover=piRover(left=leftPins, right=rightPins, pico=True)

serverRunning=True
rdata={}			# Track responses
rdataJson=""

# Check for command line arguments
# Initially can only send a '-a' to activate pico on start
if(len(sys.argv) > 1):
	if(sys.argv[1]=="-a"):
		print("Activating pico on start")
		pirover.picoActivate()
# End of argument processing

# Loop for input
while serverRunning:
	#  Wait for next request from client
	message = socket.recv().decode('utf-8')
	#print(f"Received request: {message}")
	
	# Break into CSV. Assume input is in sensible format
	csvin=message.split(',')
	# Check what command has been sent, csvin[0] should be the command
	# Make case insensitive
	cmdin=csvin[0].lower()
	numargs=len(csvin)-1		# Number of arguments supplied
	
	# Blank the internal message 
	#rdata["msg"]=""
	
	if(cmdin=="getdata"):
		# Get the latest data from the library
		rdata=pirover.getdata()
	elif(cmdin=="stop"):
		rdata=pirover.stop()
	elif(cmdin=="fwfull"):
		if(numargs>=1):
			rdata=pirover.fwFull(int(csvin[1]))
		else:
			print("Need one argument for fwfull, sent: ",message)
	elif(cmdin=="fwspeed"):
		if(numargs>=1):
			rdata=pirover.fwSpeed(int(csvin[1]))
		else:
			print("Need one argument for fwSpeed, sent: ",message)
	elif(cmdin=="chspeed"):
		if(numargs>=1):
			rdata=pirover.chSpeed(int(csvin[1]),int(csvin[2]))
		else:
			print("Need two arguments for chSpeed, sent: ",message)
	elif(cmdin=="drive"):
		if(numargs>=1):
			rdata=pirover.drive(int(csvin[1]),int(csvin[2]))
		else:
			print("Need two arguments for drive, sent: ",message)
	elif(cmdin=="js"):
		if(numargs>=1):
			rdata=pirover.js(int(csvin[1]),int(csvin[2]))
		else:
			print("Need two arguments for js, sent: ",message)
	elif(cmdin=="spin"):
		if(numargs>=1):
			rdata=pirover.spin(int(csvin[1]))
		else:
			print("Need one argument for spin, sent: ",message)
	elif(cmdin=="panangle"):
		if(numargs>=1):
			if(csvin[1]=="mid"):
				rdata=pirover.panAngle("mid")
			else:
				rdata=pirover.panAngle(int(csvin[1]))
		else:
			print("Need one argument for panangle, self: ", message)
	elif(cmdin=="panleft"):
		if(numargs>=1):
			rdata=pirover.panLeft(int(csvin[1]))
		else:
			print("Need one argument for panleft, self: ", message)
	elif(cmdin=="tiltangle"):
		if(numargs>=1):
			if(csvin[1]=="mid"):
				rdata=pirover.tiltAngle("mid")
			else:
				rdata=pirover.tiltAngle(int(csvin[1]))
		else:
			print("Need one argument for tiltangle, self: ", message)
	elif(cmdin=="tiltup"):
		if(numargs>=1):
			rdata=pirover.tiltUp(int(csvin[1]))
		else:
			print("Need one argument for tiltup, self: ", message)
	elif(cmdin=="getsens"):
		# Return all sensor data
		rdata=pirover.getSensorData()
	elif(cmdin=="getsonic"):
		# Just get sonic data, may be just one sensor
		if(numargs>=1):
			rdata["sonicDist"]=pirover.getSonic(int(csvin[1]))
		else:
			# No argument, get all ultrasonic sensors
			rdata["sonicDist"]=pirover.getSonic()
	elif(cmdin=="sendpico"):
		# Send a command to the pico
		# Collapse the CSV, removing the command off the front first
		csvin.pop(0)
		str=",".join(csvin)
		pirover.sendToPico(str)
	elif(cmdin=="checkserial"):
		# Return true or false if there is data in the queue
		# Use for testing, thread should check regularly
		print("Checking the serial buffer")
		s=pirover.checkSerial()
		print(s)
	elif(cmdin=="getpico"):
		# Gets data from the pico
		# Use for testing, thread should check regularly
		d=pirover.getFromPico()
		print(d)
	elif(cmdin=="activate"):
		# Activate the pico loop and serial receive thread
		pirover.picoActivate()
	elif(cmdin=="deactivate"):
		pirover.picoDeactivate()
	elif(message=="quit"):
		serverRunning=False
		# Also shutdown pico
		pirover.picoDeactivate()
		rdata["msg"]="Quit"
	else:
		print("Unknown command "+csvin[0])
		rdata["msg"]="Unknown command"
		
	# Produce JSON from the returned data, which we always reply with
	rdataJson=json.dumps(rdata)
	#print(rdataJson)
	byt=bytes(rdataJson, 'utf-8')
	socket.send(byt)
	
# End of serverRunning loop / main loop

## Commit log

2021-08-29 Initial motor tests and first drive demo.
2021-08-30 Modified basic motor tests
2021-08-30 Added 3d prints for batter holder, a streamer starter and driving with Blue Dot
    [18650_nickle.scad, 18650_nickle.stl]
2021-10-30 Added servo testing script
2021-11-21 Initial servo testing and driving library correction
    [driveByQueue.py, piroverlib.py, servoTest.py]
2021-11-27 Added 3d Prints for pan/tilt mount
    [hc_sr04_mount.scad, hc_sr04_mount.stl, pan_tilt_cam_arm.stl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]
2021-11-27 Connection error handling on manual client
    [hcsr04test.py, manualClient.py, panTiltWithLib.py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]
2021-12-05 Added ultrasonic sensor into queue and library
2021-12-05 Added GPIO wiring to readme
2022-01-02 Added directory for a Pico as a sensor slave
2022-01-02 Multithreadding test for the Pico
2022-01-02 Other Pico slave testing and moving all to a testing directory
2022-01-16 Elevated breadboard holder to fit more on the main board
    [elevatedBBholder.scad, elevatedBBholder.stl]
2022-01-23 Update README.md
    Added Pico wiring
2022-02-06 Updated for Pico slave
2022-02-27 Pan tilt driving via pico
2022-03-06 Added mount and schematics
    [pico_breadboard.fzz]
2022-03-06 Archive of pico code
2022-04-24 Sonic sensors and auto driving
2022-04-24 Sonic sensor mounts and Pico ultrasonic code
    [pan_tilt_mount.scad]
2022-04-24 Sonic mount and pico ultrasonics
    [overWheelSR04.scad, overWheelSR04_left.stl, overWheelSR04_right.stl]
